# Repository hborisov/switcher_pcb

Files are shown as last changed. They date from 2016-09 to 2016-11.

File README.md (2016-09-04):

# Switcher – A WiFi Open Source Power Switch and Socket

[Detailed description](http://hristoborisov.com/index.php/projects/switcher-a-wifi-open-source-power-switch/)





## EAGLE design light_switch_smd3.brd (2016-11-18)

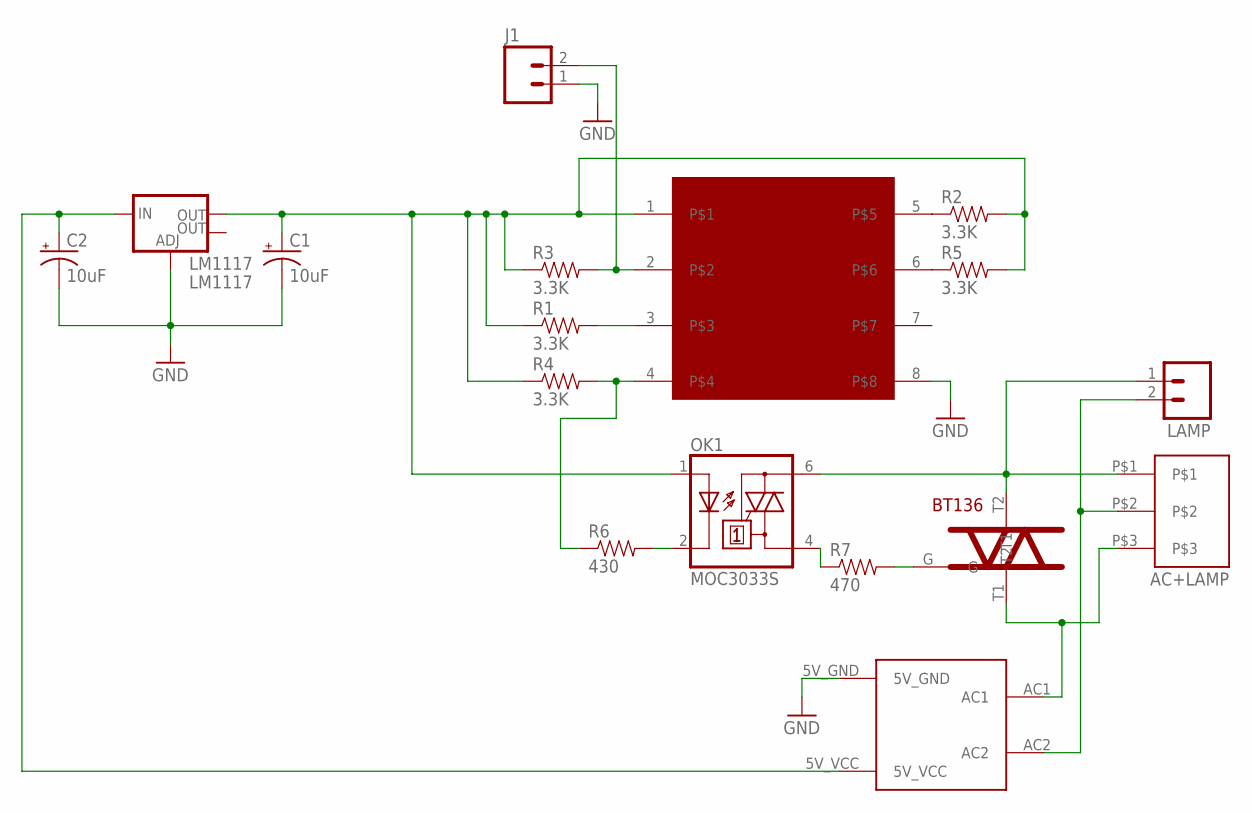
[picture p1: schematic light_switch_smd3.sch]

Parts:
AC+LAMP: DG350-3.5-03P
BT136: BT136; BT136-PKG
C1, C2: 10uF; 0603-POL
J1: M02PTH; 1X02
LAMP: M02PTH; 1X02
LM1117: LM1117; SOT223
OK1: MOC3033S; DIL6-SMD
R1, R2, R3, R4, R5: 3.3K; 0603-RES
R6: 430; 0603-RES
R7: 470; 0603-RES
U$1: HI-LINK5V-ACDC; AC5V
U$2: ESP8266-01

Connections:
GND: C1.K (-), C2.K (-), J1.1, LM1117.1 (ADJ), U$1.5V_GND, U$2.8
unnamed: J1.2, R3.2, U$2.2
unnamed: R2.1, U$2.5
unnamed: C1.A (+), LM1117.2 (OUT), OK1.1 (A), R1.1, R2.2, R3.1, R4.1, R5.2, U$2.1
unnamed: OK1.2 (C), R6.2
unnamed: BT136.G, R7.2
unnamed: OK1.4 (A1), R7.1
unnamed: AC+LAMP.P$1, BT136.T2, LAMP.1, OK1.6 (A2)
unnamed: R4.2, R6.1, U$2.4
unnamed: AC+LAMP.P$2, LAMP.2, U$1.AC2
unnamed: AC+LAMP.P$3, BT136.T1, U$1.AC1
unnamed 12: C2.A (+), LM1117.3 (IN), U$1.5V_VCC; also elsewhere on the board
unnamed 13: R5.1, U$2.6; also elsewhere on the board
unnamed: R1.2, U$2.3

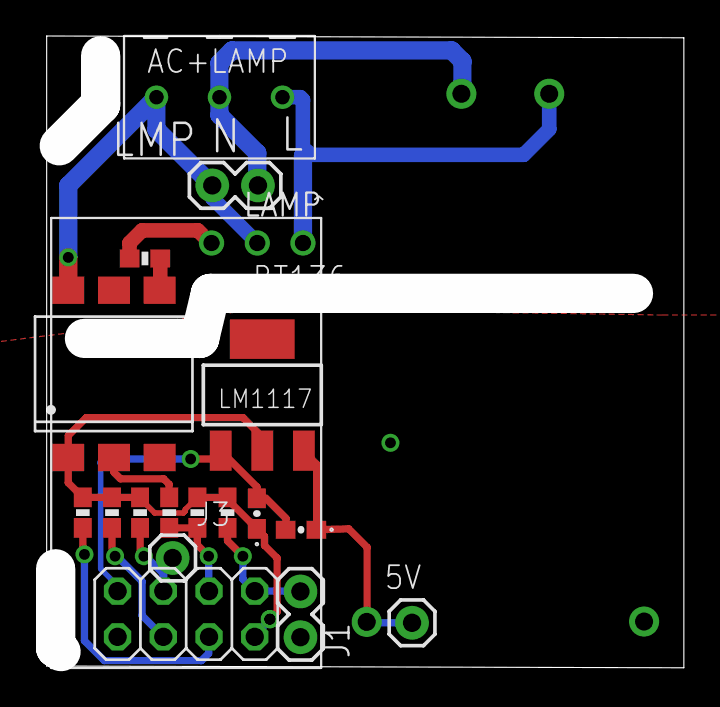
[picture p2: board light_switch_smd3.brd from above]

Board: 2 copper layers, 35.4 x 35.1 mm, 19 parts (1 on the bottom side), 14 nets.

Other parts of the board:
5V: 1X01
J3: 1X01

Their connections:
unnamed 12: 5V.1; also elsewhere on the board
unnamed 13: J3.1; also elsewhere on the board

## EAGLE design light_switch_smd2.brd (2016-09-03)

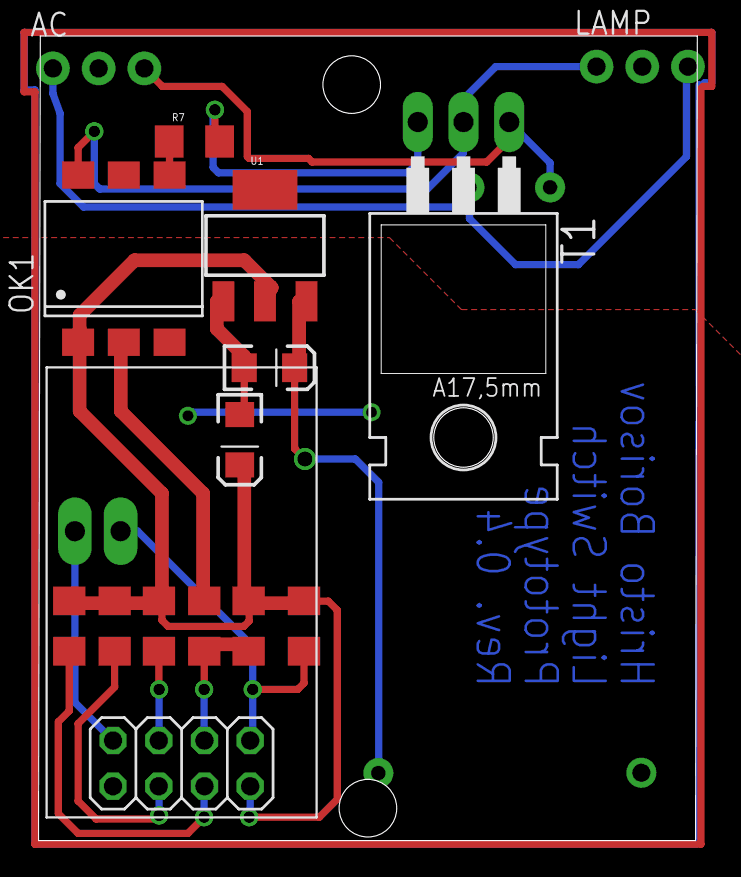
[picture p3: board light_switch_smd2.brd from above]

Board: 2 copper layers, 36.6 x 44.7 mm, 17 parts (1 on the bottom side), 14 nets.

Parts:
AC: AC; 1X03_NO_SILK
C1, C2: 10uF; EIA3216
J2: SW1; 1X02_LONGPADS
LAMP: LAMP; 1X03_NO_SILK
OK1: MOC3033S; DIL6-SMD
R1, R2, R3, R4, R5: 3.3K; 1206
R6: 430; 1206
R7: 470; 1206
T1: BT136; TO220AB
U1: LM1117; SOT223
U$1: HI-LINK5V-ACDC; AC5V
U$2: ESP8266-01

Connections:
GND: C1.C, C2.C, J2.1, U1.1, U$1.5V_GND, U$2.8
unnamed: J2.2, R3.2, U$2.2
unnamed: R2.1, U$2.5
unnamed: C1.A, OK1.1, R1.1, R2.2, R3.1, R4.1, R5.2, U1.2, U$2.1
unnamed: R1.2, U$2.3
unnamed: OK1.2, R6.2
unnamed: R7.2, T1.3
unnamed: OK1.4, R7.1
unnamed: LAMP.1, OK1.6, T1.2
unnamed: R4.2, R6.1, U$2.4
unnamed: AC.1, LAMP.3, U$1.AC2
unnamed: AC.3, T1.1, U$1.AC1
unnamed: C2.A, U1.3, U$1.5V_VCC
unnamed: R5.1, U$2.6

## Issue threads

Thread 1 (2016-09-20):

The ground plane really shouldn't cross the isolation slot

jaseg, 2016-09-20:
... because that kind of defeats the purpose of the isolation slot.

Best regards, jaseg

hborisov, 2016-09-21:
Yes, I agree. I will correct this one, thank you!

hborisov, 2016-11-18:
The issue is fixed now.

Closed 2016-11-18.

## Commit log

2016-09-03 v.2 Final
    [light_switch_smd.sch, light_switch_smd2.brd, light_switch_smd2.sch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]
2016-09-03 v.2 Final - 2
    [light_switch_smd2.brd]
2016-09-03 version 3, several correction added
    [light_switch_smd2.brd, light_switch_smd2.sch]
2016-09-03 More minor corrections.
    [light_switch_smd2.brd]
2016-09-03 pcb v4: distance between power supply pins corrected.\nSeveral vias added.
    [light_switch_smd2.brd, light_switch_smd2.sch]
2016-09-03 Version 4 revised and ready.
    [light_switch_smd3.brd, light_switch_smd3.sch]
2016-09-03 Version 5 ready and works. Minor correction on the triac placement
    [light_switch_smd3.brd]
2016-09-03 Addign milling information
    [light_switch_smd3.brd]
2016-09-03 Adding one more milling cut
    [light_switch_smd3.brd]
2016-09-03 light switch version 6 minor adjustments
    [light_switch_smd3.brd, light_switch_smd3.sch]
2016-09-03 Changing the BT136 device
    [light_switch_smd3.brd, light_switch_smd3.sch]
2016-09-03 Rev. 0.7 - Light Switch is minified and the silkscreen is cleared
    [light_switch_smd3.brd, light_switch_smd3.sch]
2016-09-03 Rev 0.8 - pcb shrinked a bit.
    [light_switch_smd3.brd, light_switch_smd3.sch]
2016-09-03 Adding labels to the power outlet
    [light_switch_smd3.brd]
2016-11-18 Fixing erroneous ground planes
    [light_switch_smd3.brd]

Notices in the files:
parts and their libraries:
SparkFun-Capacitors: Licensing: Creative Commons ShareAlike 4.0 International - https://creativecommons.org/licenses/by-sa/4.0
